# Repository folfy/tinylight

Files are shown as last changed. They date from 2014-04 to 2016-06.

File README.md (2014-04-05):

tinylight
=========

USB client for prismatik and tinylight host

Inexpensive USB Light-pack client, based on an Atmel xMega Controller.
Intended for LED Strips based on the WS2801 IC.<br>
<br>
<b>Features:</b>
- On-chip USB interface
- RGB status led
- Supply current and voltage measurement
- 6 GPIO solderpads
- PDI programming interface

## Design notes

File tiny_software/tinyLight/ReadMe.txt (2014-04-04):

========================================================================
    ANWENDUNG: tinyLight-Projektübersicht
========================================================================

Diese tinyLight-Anwendung wurde vom Anwendungs-Assistenten 
für Sie erstellt.  

Diese Datei bietet eine Übersicht über den Inhalt der einzelnen Dateien, 
aus denen Ihre tinyLight-Anwendung besteht.

tinyLight.vcxproj
    Dies ist die Hauptprojektdatei für VC++-Projekte, die mit dem 
    Anwendungs-Assistenten generiert werden. 
    Sie enthält Informationen über die Version von Visual C++, mit der die
    Datei generiert wurde, sowie über die Plattformen, Konfigurationen und 
    Projektfunktionen, die im Anwendungs-Assistenten ausgewählt wurden.

tinyLight.vcxproj.filters
    Dies ist die Filterdatei für VC++-Projekte, die mithilfe eines 
    Anwendungs-Assistenten erstellt werden. 
    Sie enthält Informationen über die Zuordnung zwischen den Dateien im 
    Projekt und den Filtern. Diese Zuordnung wird in der IDE zur Darstellung 
    der Gruppierung von Dateien mit ähnlichen Erweiterungen unter einem 
    bestimmten Knoten verwendet (z. B. sind CPP-Dateien dem Filter 
    "Quelldateien" zugeordnet).

tinyLight.cpp
    Dies ist die Hauptquelldatei der Anwendung.
    Enthält den Code zum Anzeigen des Formulars.

Form1.h
    Enthält die Implementierung der Formularklasse und der InitializeComponent()-Funktion.

AssemblyInfo.cpp
    Enthält benutzerdefinierte Attribute zum Ändern von Assemblymetadaten.

/////////////////////////////////////////////////////////////////////////////
Andere Standarddateien:

StdAfx.h, StdAfx.cpp
    Diese Dateien werden verwendet, um eine vorkompilierte Headerdatei
    (PCH-Datei) mit dem Namen "tinyLight.pch und eine 
    vorkompilierte Typendatei mit dem Namen "StdAfx.obj" zu erstellen.

/////////////////////////////////////////////////////////////////////////////

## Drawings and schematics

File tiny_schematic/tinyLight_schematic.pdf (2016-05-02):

1/1 | 1.1

## Fabian Fritzer & Martin Knapp

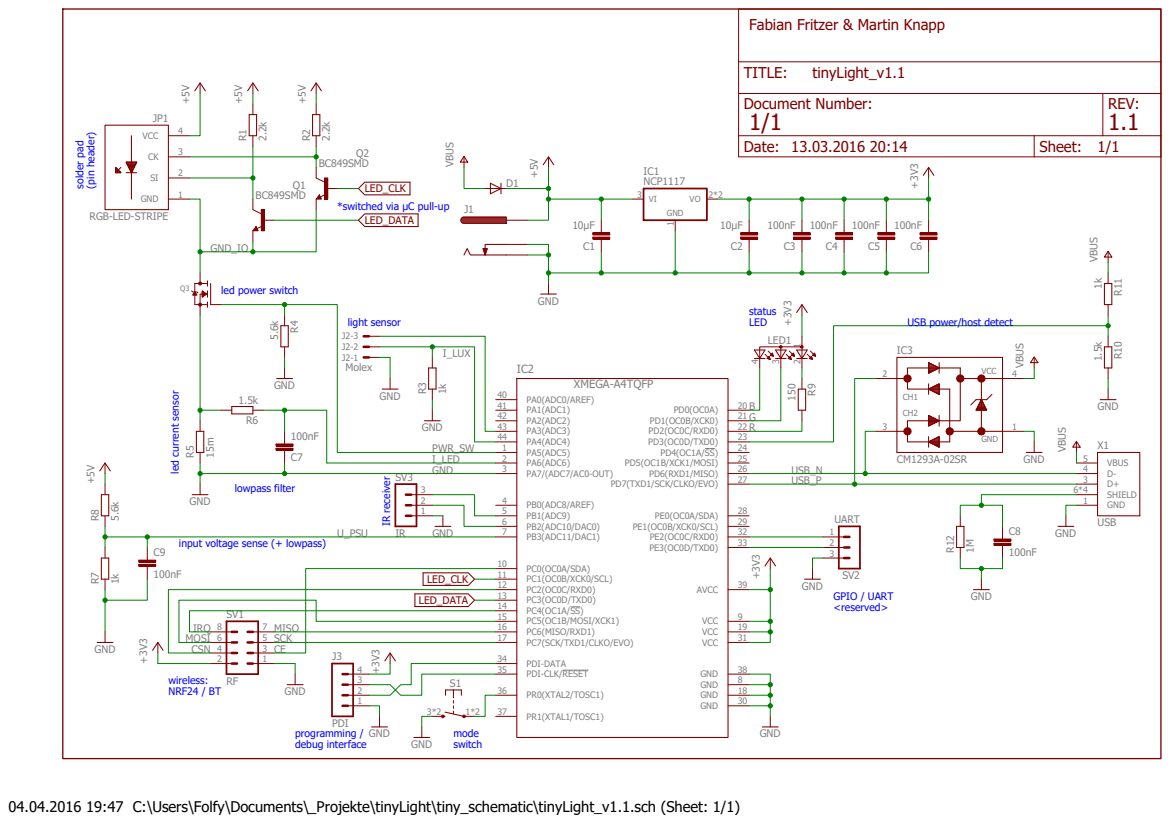
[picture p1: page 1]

USB power/host detect

04.04.2016 19:47 C:\Users\Folfy\Documents\_Projekte\tinyLight\tiny_schematic\tinyLight_v1.1.sch (Sheet: 1/1)

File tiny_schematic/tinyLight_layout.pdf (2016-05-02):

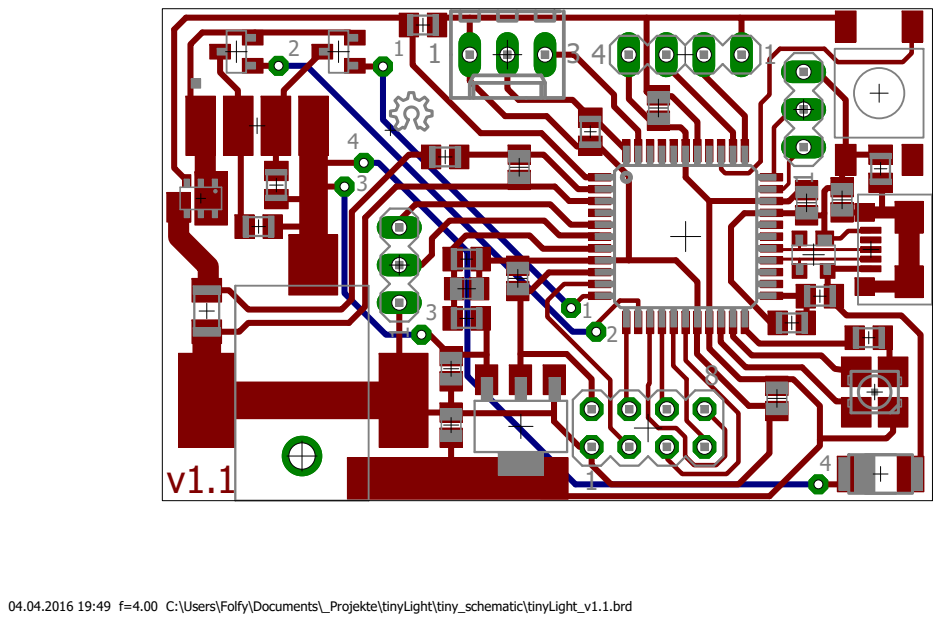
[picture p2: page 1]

04.04.2016 19:49 f=4.00 C:\Users\Folfy\Documents\_Projekte\tinyLight\tiny_schematic\tinyLight_v1.1.brd

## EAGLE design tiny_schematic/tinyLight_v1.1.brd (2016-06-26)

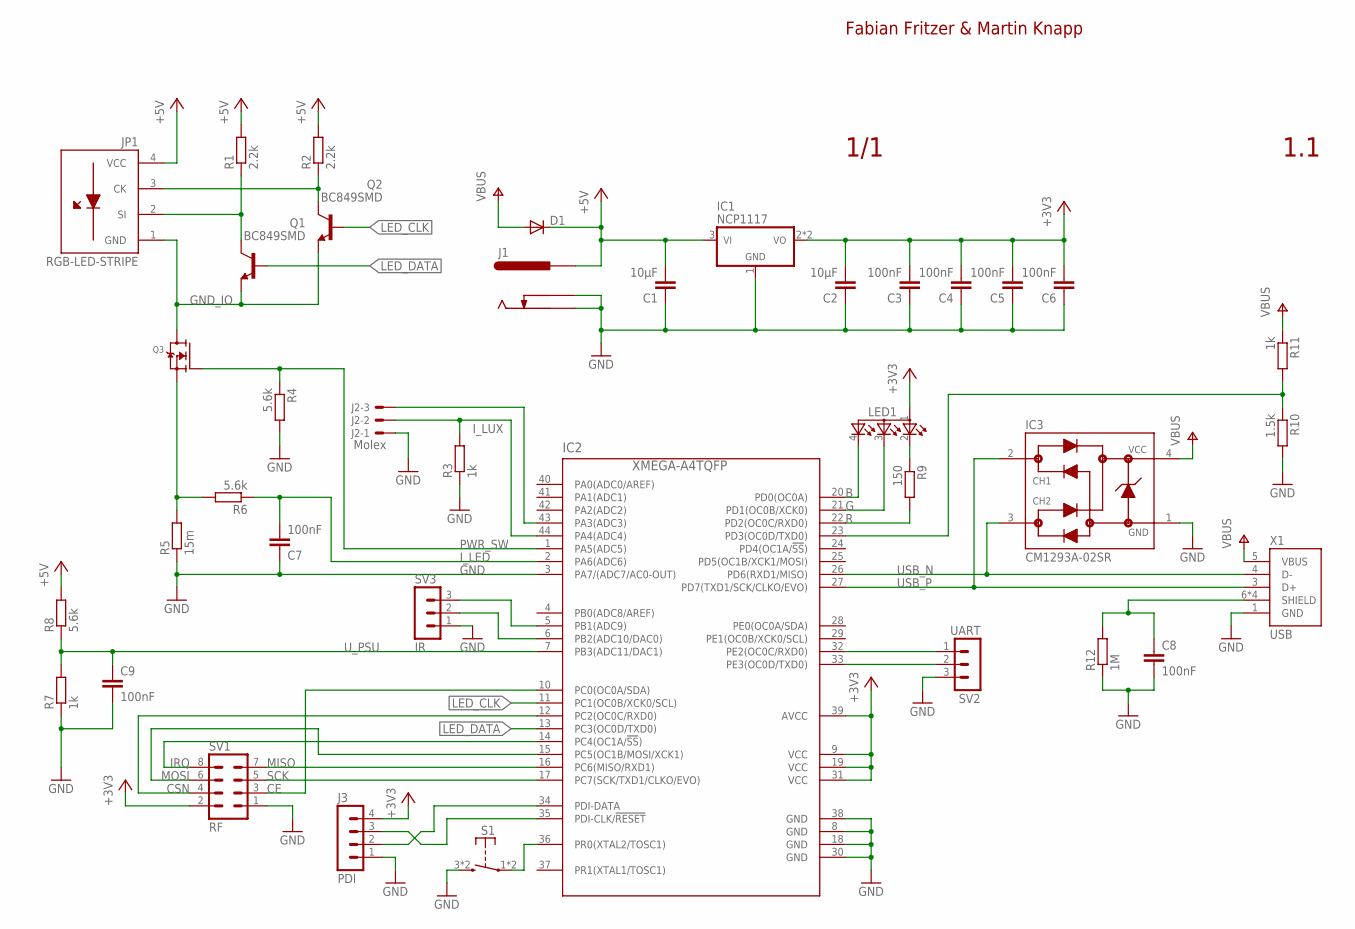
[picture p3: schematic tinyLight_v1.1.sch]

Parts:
C1, C2: 10µF; C2012
C3, C4, C5, C6, C7, C8, C9: 100nF; C2012
D1: DIODE-DO-214AC; DO-214AC
IC1: NCP1117; SOT223
IC2: XMEGA-A4TQFP; TQFP44
IC3: CM1293A-02SR; SOT143
J1: RASM722PX
J2: Molex; 6410-03
J3: PDI; MA04-1
JP1: RGB-LED-STRIPE; LED-STRIPE
LED1: RGB-LEDMINI; P-LCC-4_M
Q1, Q2: BC849SMD; SOT23-BEC
Q3: MOSFET-N; SOT457R_PHILIPS
R1, R2: 2.2k; M2012
R3, R7, R11: 1k; M2012
R4, R6, R8: 5.6k; M2012
R5: 15m; M3216
R9: 150; M2012
R10: 1.5k; M2012
R12: 1M; M2012
S1: SPST_PB; LSH_6X6
SV1: RF; MA04-2
SV2: UART; MA03-1
SV3: IR; MA03-1
X1: MICRO-USB; MIKRO_B

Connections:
+3V3: C2.2, C3.2, C4.2, C5.2, C6.2, IC1.2 (VOUT), IC1.T (VOUT), IC2.9 (VCC), IC2.19 (VCC), IC2.31 (VCC), IC2.39 (AVCC), J3.4, LED1.1 (ANODE), SV1.2
+5V: C1.2, D1.C, IC1.3 (VIN), J1.TIP, JP1.4 (VCC), R1.2, R2.2, R8.2
B: IC2.20 (PD0(OC0A)), LED1.4 (CBLUE)
CE: IC2.10 (PC0(OC0A/SDA)), SV1.3
CK: JP1.3 (CK), Q2.C, R2.1
CSN: IC2.12 (PC2(OC0C/RXD0)), SV1.4
DATA: JP1.2 (SI), Q1.C, R1.1
G: IC2.21 (PD1(OC0B/XCK0)), LED1.3 (CGREEN)
GND: C1.1, C2.1, C3.1, C4.1, C5.1, C6.1, C7.1, C8.2, C9.2, IC1.1 (GND), IC2.3 (PA7/(ADC7/AC0-OUT)), IC2.8 (GND), IC2.18 (GND), IC2.30 (GND), IC2.38 (GND), IC3.1 (GND), J1.SHUNT, J1.SLEEVE (SLEVE), J2.1, J3.1, R3.1, R4.2, R5.1, R7.1, R10.2, R12.1, S1.3 (2), S1.4 (2), SV1.1, SV2.3, SV3.1, X1.1 (GND)
GND_IO: JP1.1 (GND), Q1.E, Q2.E, Q3.1 (D), Q3.2 (D), Q3.5 (D), Q3.6 (D)
IRQ: IC2.14 (PC4(OC1A/!SS!)), SV1.8
I_LED: C7.2, IC2.2 (PA6(ADC6)), R6.1
I_LUX: IC2.44 (PA4(ADC4)), J2.2, R3.2
LED_CLK: IC2.11 (PC1(OC0B/XCK0/SCL)), Q2.B
LED_DATA: IC2.13 (PC3(OC0D/TXD0)), Q1.B
LED_R: LED1.2 (CRED), R9.1
MISO: IC2.16 (PC6(MISO/RXD1)), SV1.7
MOSI: IC2.15 (PC5(OC1B/MOSI/XCK1)), SV1.6
unnamed: IC2.6 (PB2(ADC10/DAC0)), SV3.2
unnamed: IC2.43 (PA3(ADC3)), J2.3
unnamed: IC2.33 (PE3(OC0D/TXD0)), SV2.2
unnamed: IC2.32 (PE2(OC0C/RXD0)), SV2.1
unnamed: IC2.36 (PR0(XTAL2/TOSC1)), S1.1, S1.2 (1)
unnamed: IC2.35 (PDI-CLK/!RESET), J3.3
unnamed: IC2.34 (PDI-DATA), J3.2
unnamed: IC2.5 (PB1(ADC9)), SV3.3
PWR_SW: IC2.1 (PA5(ADC5)), Q3.3 (G), R4.1
R: IC2.22 (PD2(OC0C/RXD0)), R9.2
SCK: IC2.17 (PC7(SCK/TXD1/CLKO/EVO)), SV1.5
SHIELD: C8.1, R12.2, X1.6 (SHIELD), X1.7 (SHIELD), X1.8 (SHIELD), X1.9 (SHIELD)
USB_N: IC2.26 (PD6(RXD1/MISO)), IC3.3 (CH2), X1.4 (D-)
USB_P: IC2.27 (PD7(TXD1/SCK/CLKO/EVO)), IC3.2 (CH1), X1.3 (D+)
U_PSU: C9.1, IC2.7 (PB3(ADC11/DAC1)), R7.2, R8.1
VBUS: D1.A, IC3.4 (VCC), R11.1, X1.5 (VBUS)
VBUS_LOW: IC2.23 (PD3(OC0D/TXD0)), R10.1, R11.2
VGND: Q3.4 (S), R5.2, R6.2

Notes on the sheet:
1.1
1/1
Fabian Fritzer & Martin Knapp

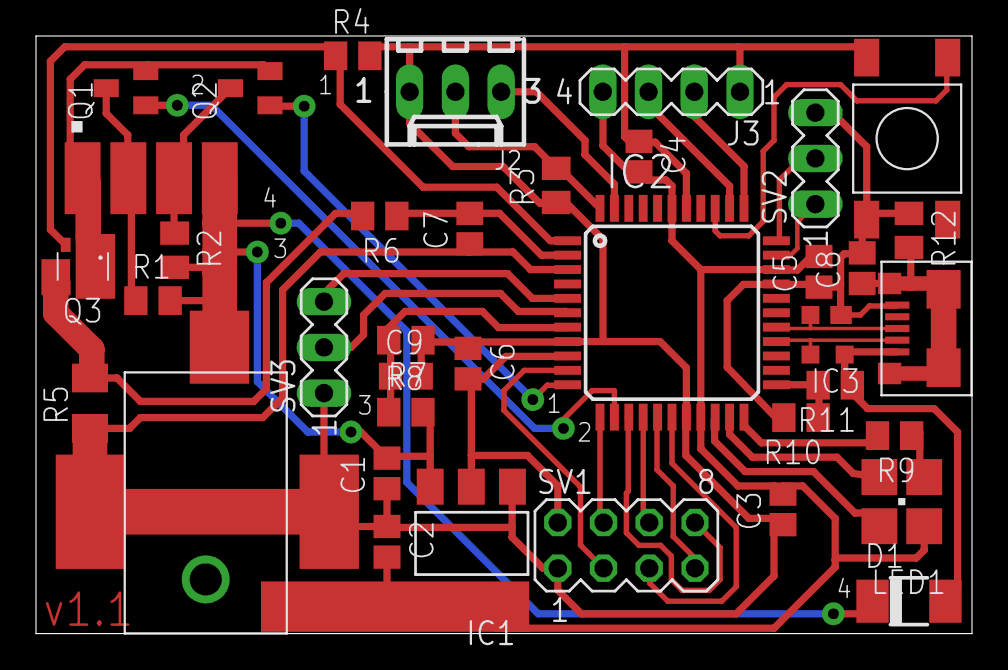
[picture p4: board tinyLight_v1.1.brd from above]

Board: 2 copper layers, 52.0 x 33.2 mm, 39 parts (0 on the bottom side), 36 nets.

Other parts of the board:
U$1: OSHW_8X100_NOTEXT

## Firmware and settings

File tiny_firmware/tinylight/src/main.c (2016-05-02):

/**
 * \file
 *
 * IO:
 *	PA1:	A_IN:		Light Sensor
 *	PA5:	D_OUT:		Power Mosfet
 *	PA6:	A_IN:		Current-Sensor +
 *	PA7:	A_IN:		Current-Sensor -
  *	PB1:	D_OUT:		IR_enable
 *	PB2:	D_IN:		IR-In
 *	PB3:	A_IN:		+5V-Sensor
 *	PC1:	D_OUT:		XCK-Led Stripe
 *	PC3:	D_OUT:		TX-Led Stripe
 *	PD0:	D_OUT:		Led blue
 *	PD1:	D_OUT:		Led green
 *	PD2:	D_OUT:		Led red
 *	PD3:	D_IN:		USB VBus Detection
 *	PD6:	D_INOUT:	USB Data -
 *	PD7:	D_INOUT:	USB Data +
 *	PE3:	D_IN:		Pushbutton
 *
 *	TCD0:	PWM Status Led
 *	TCD1:	DMA-Wait
 *
 *  EVCH0:  ADC
 */

#include <stdio.h>
#include <asf.h>
#include "libs/protocol/tiny_protocol.h"
#include "libs/interfaces/led.h"
#include "libs/interfaces/usb.h"
#include "libs/interfaces/IR.h"
#include "libs/modules/settings_sled.h"
#include "libs/modules/sleep_adc.h"

#if	RF_avail==2
	#include "BT.h"
#endif

//Button, Status_LED, FPS count
static void RTC_Alarm(uint32_t time);

int main (void)
{
	#if RF_avail==3
	PORTCFG_VPCTRLA=PORTCFG_VP02MAP_PORTC_gc;
	VPORT0_DIR|=PIN0_bm|PIN2_bm|PIN4_bm|PIN5_bm|PIN6_bm|PIN7_bm;
	#endif
	/* Init system functions (clock, sleepmgr) */
	sysclk_init();
	sleepmgr_init();
	
	/* Init mosfet_io */
	ioport_init();
	ioport_set_pin_dir(MOSFET_en, IOPORT_DIR_OUTPUT);

	sled_init();	// Init status LED
	Vbus_init();	// Init VBus detection
	ioport_set_pin_mode(BUTTON,IOPORT_MODE_PULLUP|IOPORT_MODE_INVERT_PIN);	// Init button IO
	rtc_init();		// Init RTC
	pmic_init();	// Init interrupt controller
	
	/* led init requires settings to be initialized (dma_multi-flag) */
	read_settings();
	led_init();		// Init LED strip USART as SPI Master and led latch delay timer


	rtc_set_callback(RTC_Alarm);
	rtc_set_alarm_relative(0);
	adc_init();
	cpu_irq_enable();
	usb_init();

	IR_init();
	#if	RF_avail==2
		BT_init();
	#endif
	
	while(1)
	{
		if(set.mode==MODE_SLEEP)
			power_down();
			
		#ifdef DEBUG
		uint32_t time=rtc_get_time();
		#endif
			
		handle_usb();
		handle_auto_modes();
		
		#ifdef DEBUG
		if((rtc_get_time()>=time+0.01*RTC_FREQ)&&set.mode!=MODE_SLEEP)
		;//UNDONE: implement new error handling 
		#endif
		//TODO: add rms calc -> main
	}
}

//Button, Status_LED, FPS count
static void RTC_Alarm(uint32_t time)
{
	const uint_fast16_t alarm_cycle = (RTC_TIME*RTC_FREQ+0.5);
	static uint_fast32_t alarm_prev = 0;
	rtc_button(time);
	rtc_sled();
	rtc_fps();
	rtc_usb(time);
	
	if(time > (UINT32_MAX-RTC_FREQ*3600*24))	//prevent rtc overflow if there are less than 24h remaining
	{
		if( !(set.mode&STATE_ON) || (time >= (UINT32_MAX-alarm_cycle)) )	// delay as long as required or possible
		{
			save_settings();
			reset_do_soft_reset();	// TODO: RTC_Overflow - time shift
		}
	}
	rtc_set_alarm(alarm_prev+=alarm_cycle);
}

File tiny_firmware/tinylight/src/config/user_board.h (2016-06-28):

/**
 * \file
 *
 * \brief User board definition template
 *
 * I/O Pins:
 *	PA1:	A_IN:		Light Sensor
 *	PA5:	D_OUT:		Power Mosfet
 *	PA6:	A_IN:		Current-Sensor +
 *	PA7:	A_IN:		Current-Sensor -
 *	PB1:	D_OUT:		IR_enable
 *	PB2:	D_IN:		IR-In
 *	PB3:	A_IN:		+5V-Sensor
 *	PC1:	D_OUT:		XCK-Led Stripe
 *	PC3:	D_OUT:		TX-Led Stripe
 *	PD0:	D_OUT:		Led blue
 *	PD1:	D_OUT:		Led green
 *	PD2:	D_OUT:		Led red
 *	PD3:	D_IN:		USB VBus Detection
 *	PD6:	D_INOUT:	USB Data -
 *	PD7:	D_INOUT:	USB Data +
 *  PE1:    D_OUT:      LED Data - clock (WS2811/WS2812)
 *  PE3:    D_OUT:      LED Data - data  (WS2811/WS2812)
 *	PR3:	D_IN:		Pushbutton
 *
 * Timer/counter units:
 *  TCC0:   LED (WS2811/WS2812)
 *  TCC1:	IR
 *	TCD0:	PWM Status LED
 *	TCD1:	DMA-Wait
 *
 * Event channels:
 *  EVCH0:  ADC
 *  EVCH1:  LED_CLK			(CLK, Falling edge)
 *  EVCH2:  LED_DATA		(DATA, both edges)
 *
 * DMA channels:
 *  DMACH0:	LED Timer
 *  DMACH1: LED Data
 */

 /* This file is intended to contain definitions and configuration details for
 * features and devices that are available on the board, e.g., frequency and
 * startup time for an external crystal, external memory devices, LED and USART
 * pins.
 */

#ifndef USER_BOARD_H
#define USER_BOARD_H

#include <conf_board.h>

//#define BOARD_REV 0x01			//prototype / debug board
//#define BOARD_REV 0x10			//first release
#define BOARD_REV 0x11			//reduced LED pull-up resistor value
/*	uncomment definition to select expected (wireless) module on expansion header	*/
#define RF_avail 1  			//RF-Transceiver
//#define RF_avail 2  			//BT-Transceiver
//#define RF_avail 3  			//Debug Output (remove RF module first!)
//#define UART_avail			//UART-Port
#define DEBUG					//enables reset to bootloader via button

#define SOFTWARE_REV			0x04
#define RTC_TIME				0.02	//20ms
#define BUFFER_SIZE				160

//////////////////////////////////////////////////////////////////////////
/* Internal Hardware */

#ifndef BOARD_REV
#error "BOARD_REV undefined"
#endif

#define DMA_CHANNEL_LED_TIMER	0
#define DMA_CHANNEL_LED			1
#define SLED_TIMER				TCD0
#define SPI_TIMER				TCD1
#define IR_TIMER				TCC1
#define ADC						ADCA

#define ADC_EVCH				4
#define ADC_EVCH_MUX			EVSYS_CH4MUX

#define LED_DATA_EVCH_MUX		EVSYS_CH1MUX
#define LED_DATA_EVCH_CFG		EVSYS_CH1CTRL
#define LED_TRIG_DATA			DMA_CH_TRIGSRC_EVSYS_CH1_gc


#define LED_CLK_EVCH_MUX		EVSYS_CH0MUX
#define LED_CLK_EVCH_CFG		EVSYS_CH0CTRL
#define LED_CLK_EVCH			TC_EVSEL_CH0_gc

//////////////////////////////////////////////////////////////////////////
/* Sens_Light */

#if		BOARD_REV >= 0x10
#define Sens_Light_en			IOPORT_CREATE_PIN(PORTA,3)
#define Sens_Light				IOPORT_CREATE_PIN(PORTA,4)
#define ADCCH_POS_PIN_Light		ADCCH_POS_PIN4
#elif	BOARD_REV == 0x01
#define	Sens_Light				IOPORT_CREATE_PIN(PORTA,1)
#endif

//////////////////////////////////////////////////////////////////////////
/* MOSFET, Sens_I */

#define MOSFET_en				IOPORT_CREATE_PIN(PORTA,5)

#define Sens_I_P				IOPORT_CREATE_PIN(PORTA,6)
#define ADCCH_POS_PIN_Sense		ADCCH_POS_PIN6
#define Sens_I_N				IOPORT_CREATE_PIN(PORTA,7)
#define ADCCH_NEG_PIN_Sense		ADCCH_NEG_PIN7

//////////////////////////////////////////////////////////////////////////
/* IR, Sens_Uin */

#define IR_en					IOPORT_CREATE_PIN(PORTB,2)
#define IR_in					IOPORT_CREATE_PIN(PORTB,1)
#define IR_in_int				PIN1_bm

#define Sens_Uin				IOPORT_CREATE_PIN(PORTB,3)
#define ADCCH_POS_PIN_Volt		ADCCH_POS_PIN11

//////////////////////////////////////////////////////////////////////////
/* LED_USART */

#define LED_WS281X 1

#define	LED_CLK					IOPORT_CREATE_PIN(PORTC,1)
#define	LED_TX					IOPORT_CREATE_PIN(PORTC,3)

#if		LED_WS281X==1
#if		BOARD_REV < 0x11
#warning "For old bords: WS281x requires strong pullup (short LED_CLK and LED_DATA)!"
#endif
#define	LED_XCLK				IOPORT_CREATE_PIN(PORTE,1)
#define LED_XRX					IOPORT_CREATE_PIN(PORTE,2)
#define	LED_XTX					IOPORT_CREATE_PIN(PORTE,3)
#define LED_XCLK_EVMUX			EVSYS_CHMUX_PORTE_PIN1_gc
#define LED_XTX_EVMUX			EVSYS_CHMUX_PORTE_PIN3_gc

#define LED_TC					TCC0
#define LED_TC_CC_REG			TCC0_CCBBUF
#define LED_TC_CC				TC_CCB
#define LED_TC_CCEN				TC_CCBEN

#define LED_USART				USARTE0
#define LED_USART_DATA			USARTE0_DATA
#define LED_USART_DMA_TRIG_DRE	DMA_CH_TRIGSRC_USARTE0_DRE_gc
#else
#define LED_USART				USARTC0
#define LED_USART_DATA			USARTC0_DATA
#define LED_USART_DMA_TRIG_DRE	DMA_CH_TRIGSRC_USARTC0_DRE_gc
#endif

//////////////////////////////////////////////////////////////////////////
/* RF Module */
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

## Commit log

2014-04-04 Initial Upload
    [tinyLight.brd, tinyLight.sch, tinyLight.sdf]
2014-04-04 Added Uart and Ir-Header
    [tinyLight.brd, tinyLight.sch]
2014-04-04 Improved clearance, fixed ground routing
    [tinyLight.brd]
2014-04-06 fixed new mode protocol, modified nvm_write, added status_led_off, improved readability
    [main.c, tiny_protocol.h]
2014-04-06 switch to save_settings()
2014-04-07 Revert "switch to save_settings()"
    This reverts commit 927088e2ddb63b11052bca827abe539d1d2756bf.
    [main.c]
2014-04-07 added documentation
    [protocol.xlsx]
2014-04-07 fixed usb mode - buffer gamma mapping
    [main.c]
2014-04-07 BT Modul added
    [BT.brd, BT.sch, tinyLight.brd]
2014-04-08 Fixed eesave, disabled power down and gamma_calc
    [main.c]
2014-04-09 Added IR-Decoder Detection not working
    [main.c, tiny_protocol.h, user_board.h]
2014-04-10 fixed gamma_calc, disabled IR
    [main.c, user_board.h]
2014-04-12 BT-Module finished IR-header moved
    [BT.brd, BT.sch, tinyLight.brd]
2014-04-13 Improved clearance
    [tinyLight.brd]
2014-04-14 close #4
    [tinyLight.brd]
2014-04-15 final board (hopefully...)
    [tinyLight.brd, tinyLight.sch]
2014-04-17 added revision reference, RF net names, fixed cap value
    [tinyLight.brd, tinyLight.sch]
2014-04-17 fixed protocol, minor protocol update
    [protocol.xlsx]
2014-04-17 bugfix, updated protocol_rev, changed cmd_test response
    [protocol.xlsx]
2014-04-17 changed board_rev
2014-04-17 fixed colorswirl, added settings preset, minor improvements
    [tinyLight.brd, tinyLight.sch]
2014-04-18 added usb reset
    [protocol.xlsx]
2014-04-18 bootloader ported to new hardware
    [tinyLight.brd, tinyLight.sch]
2014-04-20 BT implemented
    [BT.brd, BT.sch]
2014-04-20 dozens of small fixes and improvements, added brownout prevention, adc wip, usb and gamma done
    [protocol.xlsx]
2014-04-20 added new protocol doc (prevent merge problems)
    [protocol.xlsx]
2014-04-21 exported led functions -> led.h
2014-04-21 exported settings / sled, misc / adc functions -> set_sled, misc_adc lib
    [protocol.xlsx]
2014-04-23 last changes noted
    [protocol.xlsx]
2014-04-29 inplemented debug tools, reduced adc sample rate, added alpha control, added max value log, removed old error handling, rewrote sled control, fixed ada
    [protocol.xlsx, tinyLight.sdf]
2014-04-29 IR fixed and exported
    [main.c]
2014-04-29 exported bt, fixed ir not avail, removed improper extern declerations
    [main.c]
2014-04-30 fixed IR, added new single-color-mode, corrected doc
    [protocol.xlsx]
2014-04-30 Defined IR timer in user_board
2014-05-01 Bugfix usb_mode timeout
    [protocol.xlsx]
2014-05-02 BT-layout changed, sleeping status value implemented, IR-alpha implemented
    [BT.brd, BT.sch]
2014-05-18 -(Bugfix) USB Raw mode -Gamma .05 settings resolution -Variable FPS Limit -(Bugfix) Light measurement (x1/2 gain seems to add a big negative offset, hw-bug?)
    [protocol.xlsx]
2014-07-10 BT-driver implemented, fixed count (Not tested)
    [main.c, user_board.h]
2016-03-01 Added comments to schematic; created pdf board documentation
    [tinyLight.brd, tinyLight.sch]
2016-04-04 new board layout added (use usb as alternative power source via diode)
    [tinyLight_v1.1.brd, tinyLight_v1.1.sch]
2016-04-04 Migrated to AtmelStudio 7 and ASF 3.21.0; Organized IR-Code (now mandatory); Split global init-file into libs; Moved user_board.h into root-dir (so asf-dir contains no configuration anymore); USB: bu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
2016-05-02 *BUGFIXES* (from last two commits)
    [main.c, tiny_protocol.h, user_board.h]
2016-05-02 stripped down led usart setup code
2016-05-02 Revert "RF essentials WIP"
    This reverts commit d9e858a75cbe4ba289f600f370b0089ab7043307.
    [led.c, user_board.h]
2016-06-26 Working WS281x implementation (ToDo: Regression Tests)
    [tinyLight_v1.1.brd, tinyLight_v1.1.sch]
2016-06-26 minor bugfixes; simplified ADC oversampling
2016-06-28 Minor tweaks, regression bugfixes
    [user_board.h]
